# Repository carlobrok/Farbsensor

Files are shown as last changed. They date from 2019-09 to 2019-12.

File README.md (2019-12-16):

# RGB Farbsensor

Analoger RGB Farbsensor entwickelt für den Robo-Cup Rescue Line.

Library für den Sensor: https://github.com/carlobrok/Sensorleiste

### Eigenschaften

* 10,5 mm x 17,7 mm
* 6 Pins
* M3 Loch
* Sehr helle RGB LED
* Analoge Spannung als Helligkeitswert
* SMD-Komponenten
* Günstig

### Pinbelegung

Pin  | Funktion
-----|---------
GND  | Ground / Masse
5V   | 5V Photodiode
SEN  | Spannung der Photodiode
R    | 5V Rote LED (50 mA)
G    | 5V Grüne LED (35 mA)
B    | 5V Blaue LED (30 mA)

### Bauteile

Bauteil | Menge |   Name / Link
-------|--|---------------
LED  | 1 | [Nichia NSSM124DT](https://www.leds.de/nichia-nssm124dt-smd-led-rgb-30201.html)
Photodiode | 1 | [SFH-2711](https://www.mouser.de/ProductDetail/OSRAM-Opto-Semiconductors/SFH-2711?qs=%252BEew9%252B0nqrDd5IpctorHnA==)
Transistor | 1 | [BCW32](https://www.digikey.de/product-detail/de/on-semiconductor/BCW32LT1G/BCW32LT1GOSCT-ND/2704971)
Pins | 1 | [3x2 Steckleiste](https://www.digikey.de/product-detail/de/amphenol-icc-fci/67997-206HLF/609-3234-ND/1878491)
R1 | 1 | [100k](https://www.digikey.de/product-detail/de/yageo/RC0603FR-07100KL/311-100KHRCT-ND/729836)
R2 | 1 | [147](https://www.digikey.de/product-detail/de/yageo/RC0603FR-07147RL/311-147HRCT-ND/729897)
R3/R4 | 2 | [100](https://www.digikey.de/product-detail/de/yageo/RT0603BRD07100RL/YAG1497CT-ND/5138945)

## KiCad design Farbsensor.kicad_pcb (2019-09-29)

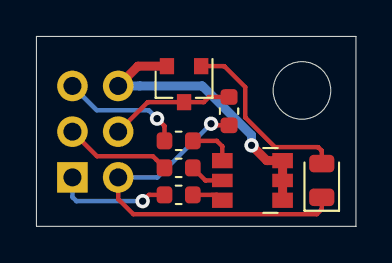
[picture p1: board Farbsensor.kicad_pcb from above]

Board: 2 copper layers, 17.8 x 10.5 mm, 9 parts (1 on the bottom side), 10 nets.

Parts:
D1: SFH2711; D_0805_2012Metric
D2: NSSM124DT; LED_NSSM124D_4.5x3.05mm
H1: MountingHole; MountingHole_3.2mm_M3_DIN965
J1: Conn_02x03_Odd_Even; PinHeader_2x03_P2.54mm_Vertical
Q1: BCW32; SOT-23
R1: 100k; R_0603_1608Metric
R2: 147; R_0603_1608Metric
R3, R4: 100; R_0603_1608Metric

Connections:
+5V: D1.1, J1.2, R1.1
/B: D2.6, R2.2
/G: D2.5, R3.2
/LED_B: J1.1, R2.1
/LED_G: J1.3, R3.1
/LED_R: J1.5, R4.1
/R: D2.4, R4.2
/SEN: J1.4, Q1.3, R1.2
GND: D2.1, D2.2, D2.3, J1.6, Q1.2
unnamed: D1.2, Q1.1

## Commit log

2019-08-22 Add KiCad project
    [Farbsensor.kicad_pcb, Farbsensor.sch]
2019-08-22 changed pcb layout, switched pin assignment
    [Farbsensor.kicad_pcb, Farbsensor.sch]
2019-08-24 changed pin header assignment
    [Farbsensor.sch]
2019-08-24 changed pin header assignment, moved resistor
    [Farbsensor.kicad_pcb]
2019-08-24 Added outline drawing of LED
2019-09-13 Layout überarbeitet, Beschriftungsfehler behoben
    [Farbsensor.kicad_pcb, Farbsensor.sch]
2019-09-29 Beschriftung geändert
    [Farbsensor.kicad_pcb]
